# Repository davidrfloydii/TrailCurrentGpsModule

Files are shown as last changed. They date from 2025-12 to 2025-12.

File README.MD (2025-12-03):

# Project Overview
This project is a stand alone GNSS module that utlizes the DFRobot Gravity GNSS receiver. The data that comes in is then formatted and sent over the CAN bus for other modules to use.

Some example use cases are:
-  Digital Clocks
-  Navigation devices
-  Geospatial macros that control devices based on pinned locations

## Enums for GNSS Mode
 -- 1   eGPS              use gps
 -- 2   eBeiDou           use beidou
 -- 3   eGPS_BeiDou       use gps + beidou
 -- 4   eGLONASS          use glonass
 -- 5   eGPS_GLONASS      use gps + glonass
 -- 6   eBeiDou_GLONASS   use beidou +glonass
 -- 7   eGPS_BeiDou_GLONASS use gps + beidou + glonass

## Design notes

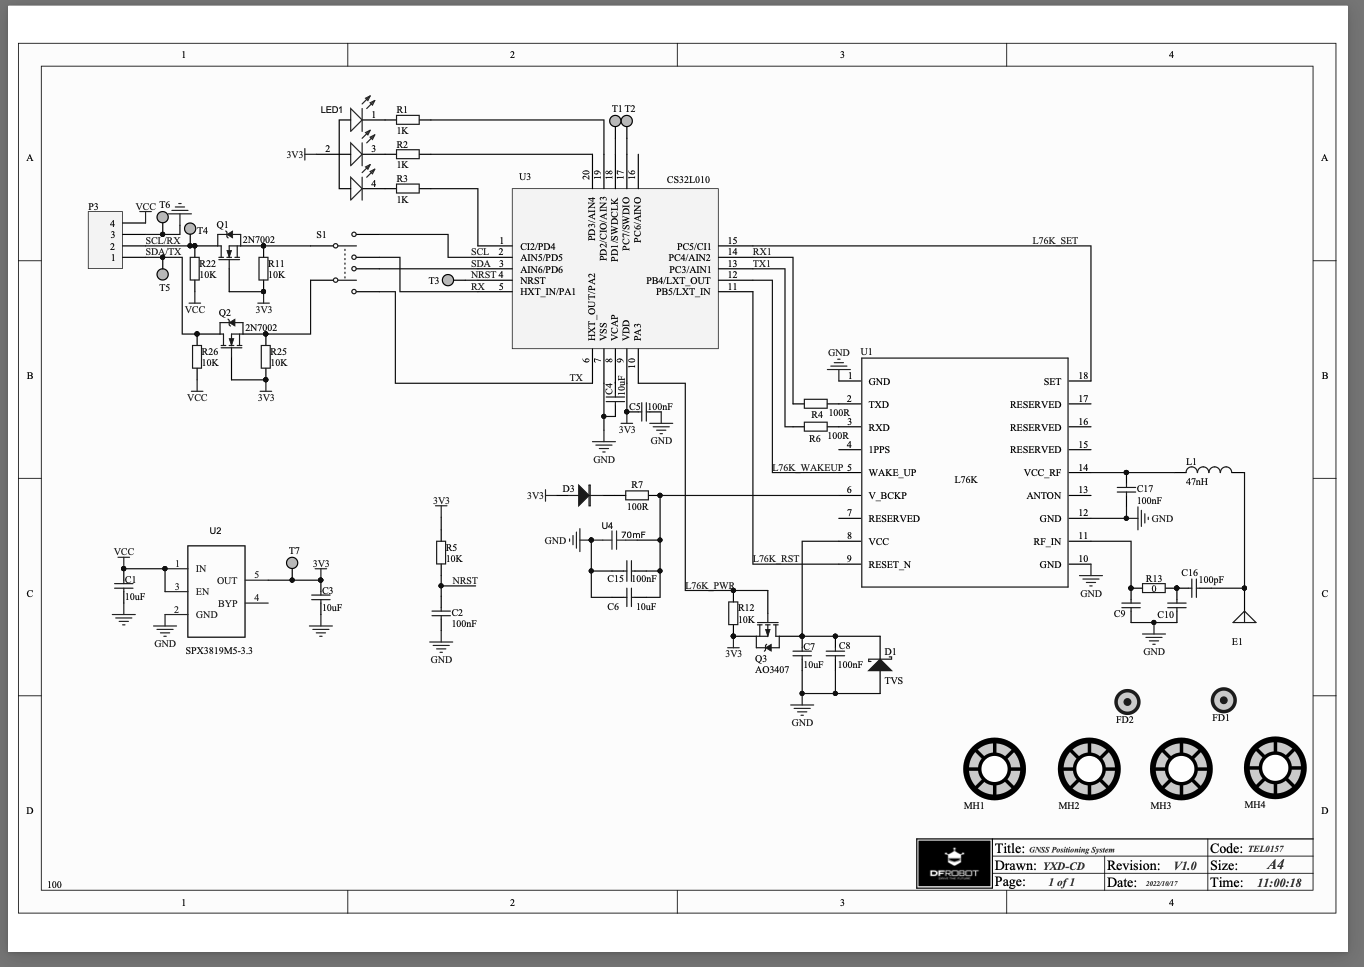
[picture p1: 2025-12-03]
EDA/DFRobot_Gnss_Schematic.png

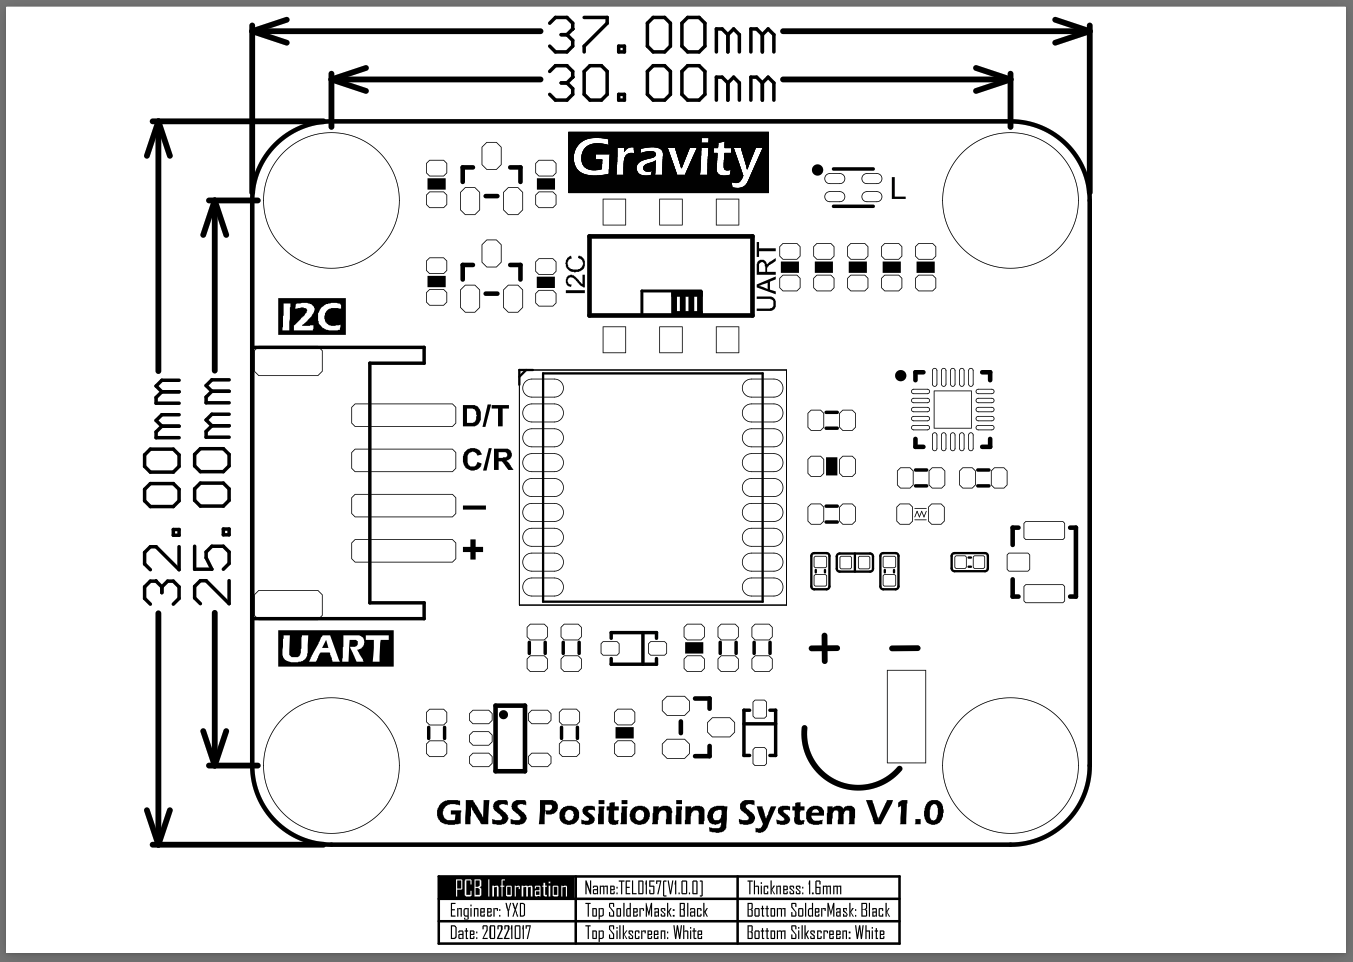
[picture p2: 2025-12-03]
CAD/DFRobotGnss.png

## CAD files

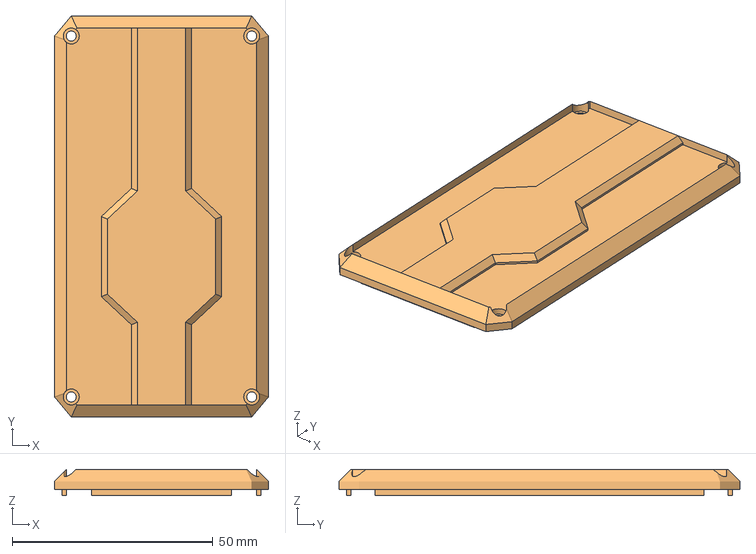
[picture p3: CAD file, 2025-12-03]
CAD/trailcurrent-gps-module-housing.FCStd
53.4 x 100.0 x 6.50 mm
BodyCaseCover
BodyCaseCover (Meshed)

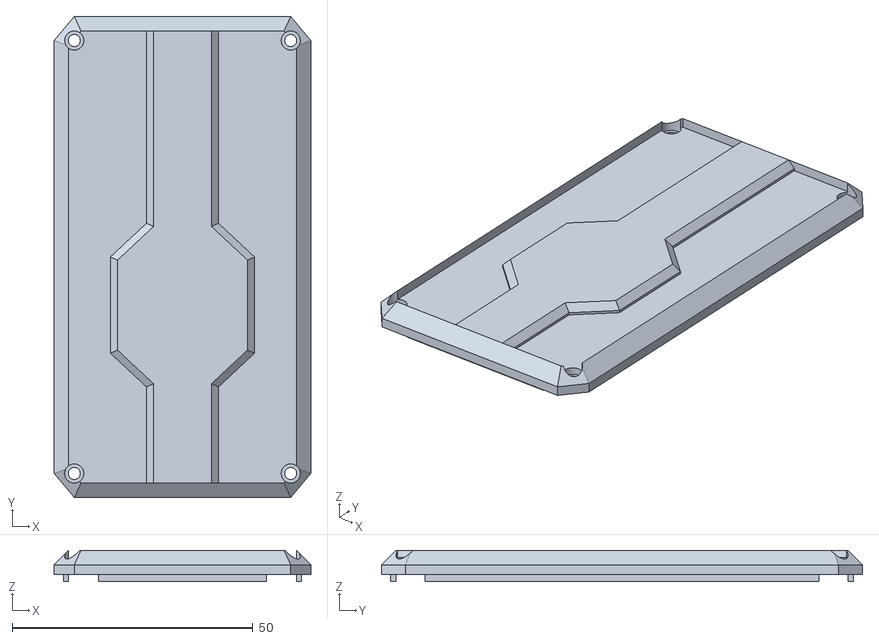
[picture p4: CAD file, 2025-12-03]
CAD/BodyCaseCover.stl
53.4 x 100.0 x 6.50

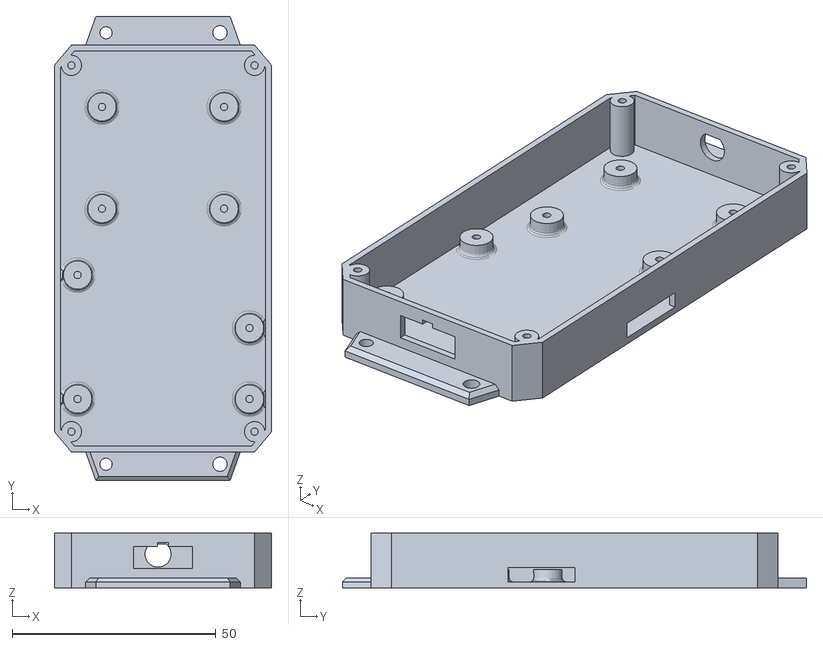
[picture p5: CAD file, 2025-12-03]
CAD/BodyCaseBottom.stl
53.4 x 114.0 x 13.5

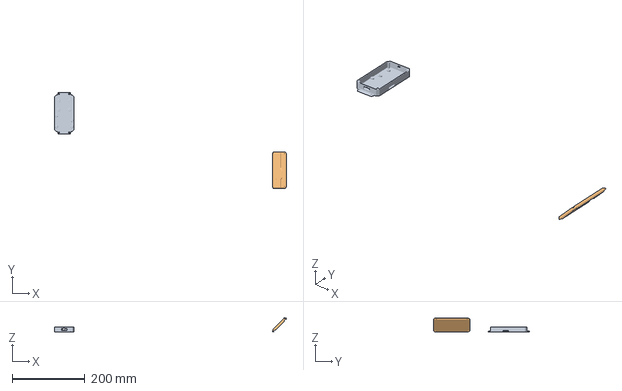
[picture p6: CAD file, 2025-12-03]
CAD/TrailCurrentGpsModuleCaseBottom.3mf
637.7 x 263.6 x 39.2 mm
BodyCaseBottomV4.stl
BodyCaseCover.stl

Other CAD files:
CAD/TrailCurrentGpsModuleCase.3mf

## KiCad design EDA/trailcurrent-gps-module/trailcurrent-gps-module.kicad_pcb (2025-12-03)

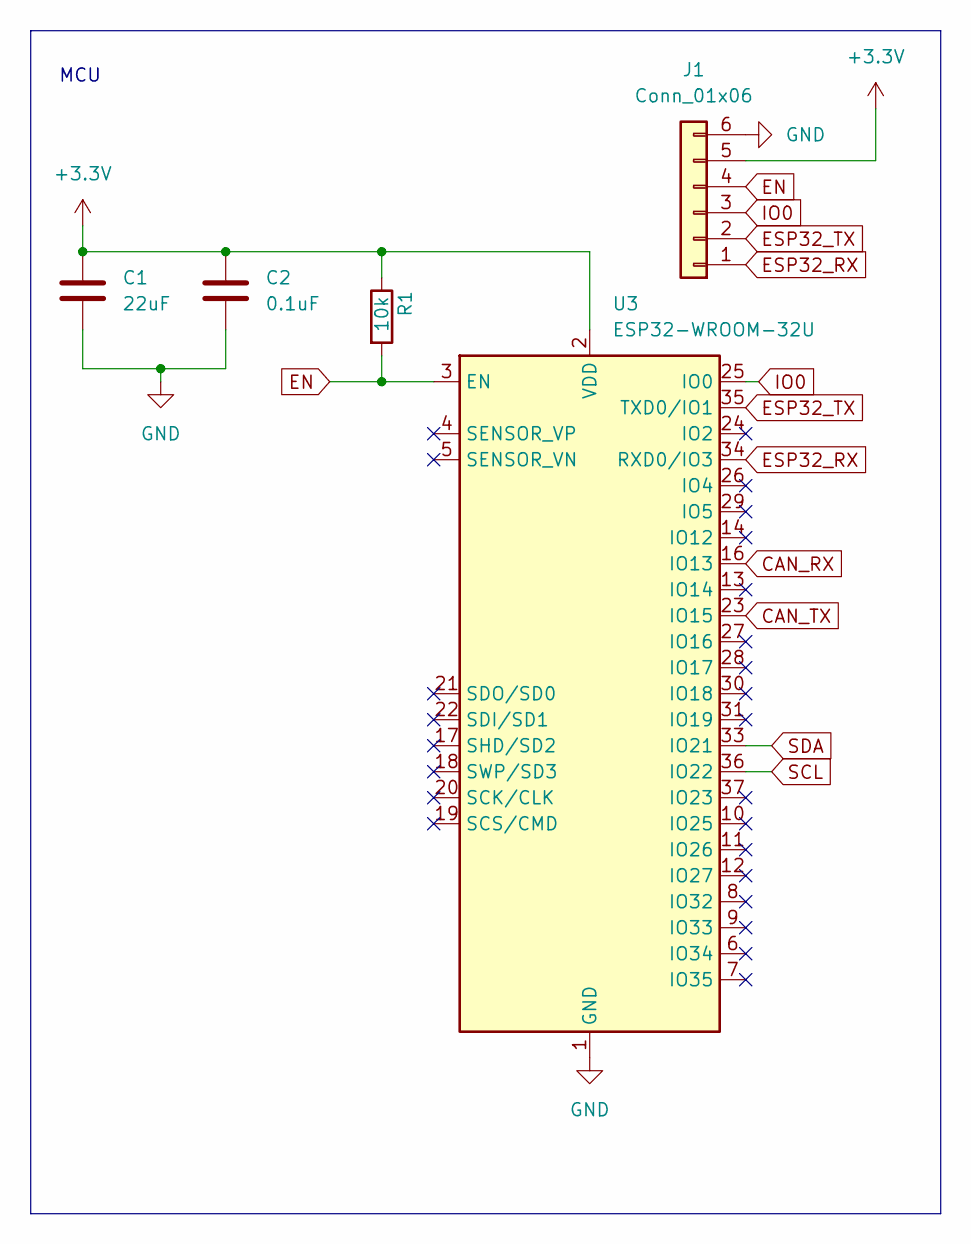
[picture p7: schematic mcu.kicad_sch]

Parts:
C1: 22uF; C_1206_3216Metric_Pad1.33x1.80mm_HandSolder
C2: 0.1uF; C_1206_3216Metric_Pad1.33x1.80mm_HandSolder
J1: Conn_01x06; PinHeader_1x06_P2.54mm_Horizontal
R1: 10k; R_1206_3216Metric_Pad1.30x1.75mm_HandSolder
U3: ESP32-WROOM-32U

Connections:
+3.3V: C1.1, C2.1, J1.5, R1.1, U3.2 (VDD); also elsewhere on the board
CAN_RX: U3.16 (IO13); also elsewhere on the board
CAN_TX: U3.23 (IO15); also elsewhere on the board
EN: J1.4, R1.2, U3.3 (EN)
ESP32_RX: J1.1, U3.34 (RXD0/IO3)
ESP32_TX: J1.2, U3.35 (TXD0/IO1)
GND: C1.2, C2.2, J1.6, U3.1 (GND), U3.15 (GND), U3.38 (GND), U3.39 (GND); also elsewhere on the board
IO0: J1.3, U3.25 (IO0)
SCL: U3.36 (IO22); also elsewhere on the board
SDA: U3.33 (IO21); also elsewhere on the board

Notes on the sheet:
MCU

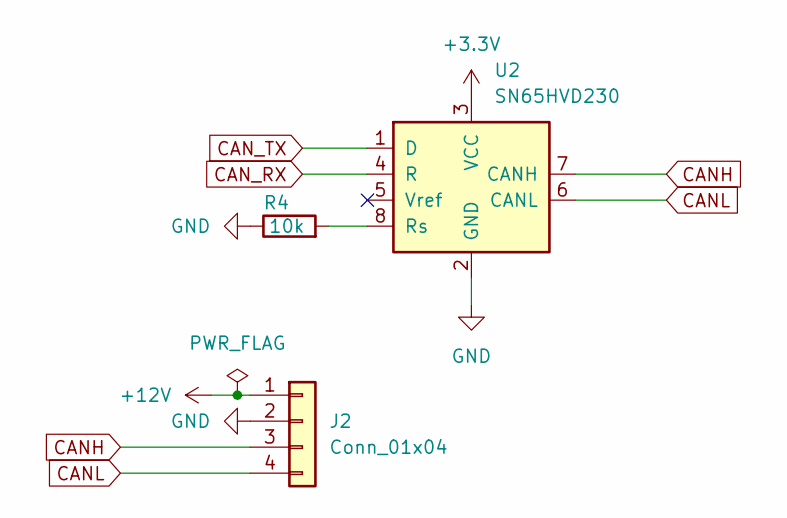
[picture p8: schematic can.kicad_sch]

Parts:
J2: Conn_01x04; CAN_PLUS_POWER
R4: 10k; R_1206_3216Metric_Pad1.30x1.75mm_HandSolder
U2: SN65HVD230; SOIC-8_3.9x4.9mm_P1.27mm

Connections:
+3.3V: U2.3 (VCC); also elsewhere on the board
+12V: J2.1; also elsewhere on the board
CANH: J2.3, U2.7 (CANH)
CANL: J2.4, U2.6 (CANL)
CAN_RX: U2.4 (R); also elsewhere on the board
CAN_TX: U2.1 (D); also elsewhere on the board
GND: J2.2, R4.1, U2.2 (GND); also elsewhere on the board
unnamed: R4.2, U2.8 (Rs)

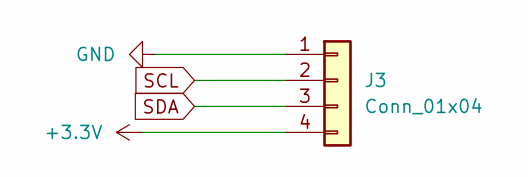
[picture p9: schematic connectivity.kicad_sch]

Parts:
J3: Conn_01x04; GenericPad_01x04

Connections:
+3.3V: J3.4; also elsewhere on the board
GND: J3.1; also elsewhere on the board
SCL: J3.2; also elsewhere on the board
SDA: J3.3; also elsewhere on the board

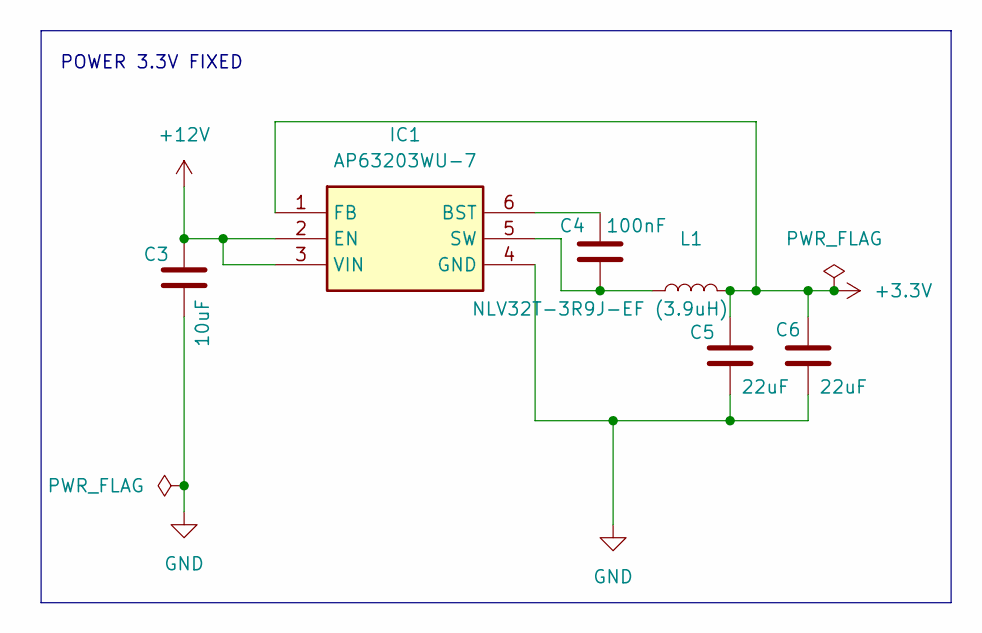
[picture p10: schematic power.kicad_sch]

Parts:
C3: 10uF; C_1206_3216Metric
C4: 100nF; C_1206_3216Metric
C5, C6: 22uF; C_1206_3216Metric_Pad1.33x1.80mm_HandSolder
IC1: AP63203WU-7; AP63203WU7; Mouser Part Number 621-AP63203WU-7
L1: NLV32T-3R9J-EF (3.9uH); NLV32T-3R9J-EF

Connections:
+3.3V: C5.1, C6.1, IC1.1 (FB), L1.2; also elsewhere on the board
+12V: C3.1, IC1.2 (EN), IC1.3 (VIN); also elsewhere on the board
GND: C3.2, C5.2, C6.2, IC1.4 (GND); also elsewhere on the board
unnamed: C4.1, IC1.6 (BST)
unnamed: C4.2, IC1.5 (SW), L1.1

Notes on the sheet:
POWER 3.3V FIXED

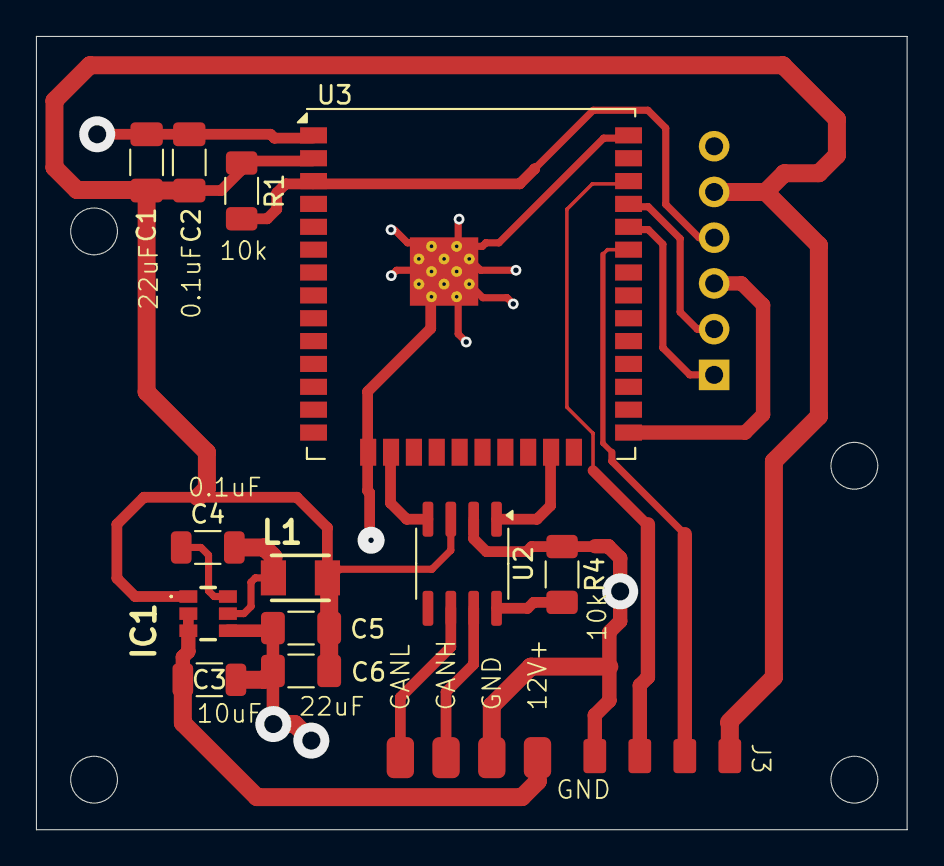
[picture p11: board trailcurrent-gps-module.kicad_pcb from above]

Board: 2 copper layers, 48.4 x 44.1 mm, 15 parts (1 on the bottom side), 16 nets.

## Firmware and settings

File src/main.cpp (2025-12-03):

#include "globals.h"
#include "i2cGps.h"
#include "canHelper.h"

uint16_t currentYear = 0;
uint8_t currentMonth = 0;
uint8_t currentDay = 0;
uint8_t currentHour = 0;
uint8_t currentMinute = 0;
uint8_t currentSecond = 0;
float currentLatitude = 0.0;
float currentLongitude = 0.0;
double currentAltitude = 0.0;
uint8_t currentNumSatUsed = 0;
double currentSpeedOverGround = 0.0;
double currentCourseOverGround = 0.0;
uint8_t currentGnssMode = 0;

unsigned long updateStartMillis;
unsigned long currentUpdateMillis;
const unsigned long updateIntervalMillis = 100;

void setup()
{
  Serial.begin(115200);
  i2cGps::setup();
  canHelper::setup();
}

void loop()
{
  currentUpdateMillis = millis();
  if (currentUpdateMillis - updateStartMillis >= updateIntervalMillis)
  {
    i2cGps::getGnssData(currentYear, currentMonth, currentDay, currentHour, currentMinute, currentSecond, currentLatitude, currentLongitude, currentAltitude, currentNumSatUsed, currentSpeedOverGround, currentCourseOverGround, currentGnssMode);
    canHelper::sendGnssData(currentYear, currentMonth, currentDay, currentHour, currentMinute, currentSecond, currentLatitude, currentLongitude, currentAltitude, currentNumSatUsed, currentSpeedOverGround, currentCourseOverGround, currentGnssMode);
    updateStartMillis = currentUpdateMillis;
  }
}

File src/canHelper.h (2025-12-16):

#pragma once
#include <Arduino.h>
#include "globals.h"
#include "driver/twai.h"

#define CAN_RX 13
#define CAN_TX 15
#define POLLING_RATE_MS 100
static bool driver_installed = false;
#define CAN_SEND_MESSAGE_LATLON_IDENTIFIER 0x009;
#define CAN_SEND_MESSAGE_DATETIME_IDENTIFIER 0x006;
#define CAN_SEND_MESSAGE_SATNUM_SPEED_COURSE_GNSSMODE_IDENTIFIER 0x007;
#define CAN_SEND_MESSAGE_ALTITUDE_IDENTIFIER 0x008;

namespace canHelper
{
    void setup()
    {
        twai_general_config_t g_config = TWAI_GENERAL_CONFIG_DEFAULT((gpio_num_t)CAN_TX, (gpio_num_t)CAN_RX, TWAI_MODE_NO_ACK);
        twai_timing_config_t t_config = TWAI_TIMING_CONFIG_500KBITS(); // Look in the api-reference for other speed sets.
        // THIS IS A FILTER THAT ENSURES TRANSMIT ONLY
        twai_filter_config_t f_config = {
            .acceptance_code = 0xFFFFFFFF, // Base ID = 0
            .acceptance_mask = 0x00000000, // Match exactly against the mask
            .single_filter = true          // Single filter mode
        };
        // twai_filter_config_t f_config = TWAI_FILTER_CONFIG_ACCEPT_ALL();
        //  Install TWAI driver
        if (twai_driver_install(&g_config, &t_config, &f_config) == ESP_OK)
        {
            debugln("Driver installed");
        }
        else
        {
            debugln("Failed to install driver");
            return;
        }

        // Start TWAI driver
        if (twai_start() == ESP_OK)
        {
            debugln("Driver started");
        }
        else
        {
            debugln("Failed to start driver");
            return;
        }

        // Reconfigure alerts to detect frame receive, Bus-Off error and RX queue full states
        uint32_t alerts_to_enable = TWAI_ALERT_RX_DATA | TWAI_ALERT_ERR_PASS | TWAI_ALERT_BUS_ERROR | TWAI_ALERT_RX_QUEUE_FULL;
        if (twai_reconfigure_alerts(alerts_to_enable, NULL) == ESP_OK)
        {
            debugln("CAN Alerts reconfigured");
        }
        else
        {
            debugln("Failed to reconfigure alerts");
            return;
        }

        // TWAI driver is now successfully installed and started
        driver_installed = true;
    }

    byte latBytes[4];
    byte lonBytes[4];
    byte latLonByteAry[8];
    byte dateTimeByteAry[8];
    byte courseOverGroundByteAry[2];
    byte speedOverGroundByteAry[2];
    byte altitudeByteAry[4];
    // Endcode a latitude or longitude float value into a 4-byte array with the first byte as sign
    void encodeLatOrLonValue(float f, byte out[4])
    {
        // Sign byte
        out[0] = (f < 0) ? 1 : 0;
        if (f < 0)
            f = -f;

        // Scale and round
        uint32_t scaled = (uint32_t)(f * 10000.0f + 0.5f);

        // Store 24-bit integer
        out[1] = (scaled >> 16) & 0xFF;
        out[2] = (scaled >> 8) & 0xFF;
        out[3] = scaled & 0xFF;
    }
    // Decode a latitude or longitude float value from a 4-byte array with the first byte as sign
    float decodeLatOrLonValue(const byte in[4])
    {
        uint32_t scaled =
            ((uint32_t)in[1] << 16) |
            ((uint32_t)in[2] << 8) |
            (uint32_t)in[3];

        float f = scaled / 10000.0f;
        if (in[0] == 1)
            f = -f;
        debuglnf(f, 5);
        return f;
    }
    // Method that can be used to decode date and time data from a CAN message
    void decodeDateTimeData(const byte in[8], uint16_t &year, uint8_t &month, uint8_t &day, uint8_t &hour, uint8_t &minute, uint8_t &second)
    {
        year = ((uint16_t)in[0] << 8) | (uint16_t)in[1];
        month = in[2];
        day = in[3];
        hour = in[4];
        minute = in[5];
        second = in[6];
    }
    // Method that can be used to decode altitude data from a CAN message
    void decodeAltitudeData(const byte in[4])
    {
        double altitude = 0.0;
        uint32_t scaled =
            ((uint32_t)in[0] << 24) |
            ((uint32_t)in[1] << 16) |
            ((uint32_t)in[2] << 8) |
            (uint32_t)in[3];
        altitude = scaled / 100.0;
    }

    void formatDateTimeData(uint16_t year, uint8_t month, uint8_t day, uint8_t hour, uint8_t minute, uint8_t second)
    {
        // Implementation for formatting date and time data into CAN message
        dateTimeByteAry[0] = (year >> 8) & 0xFF;
        dateTimeByteAry[1] = year & 0xFF;
        dateTimeByteAry[2] = month;
        dateTimeByteAry[3] = day;
        dateTimeByteAry[4] = hour;
        dateTimeByteAry[5] = minute;
        dateTimeByteAry[6] = second;
        dateTimeByteAry[7] = 0; // Reserved for future use or padding
    }

    void formatLatLongData(float latitude, float longitude)
    {
        encodeLatOrLonValue(latitude, canHelper::latBytes);
        encodeLatOrLonValue(longitude, canHelper::lonBytes);
        latLonByteAry[0] = latBytes[0];
        latLonByteAry[1] = latBytes[1];
        latLonByteAry[2] = latBytes[2];
        latLonByteAry[3] = latBytes[3];
        latLonByteAry[4] = lonBytes[0];
        latLonByteAry[5] = lonBytes[1];
        latLonByteAry[6] = lonBytes[2];
        latLonByteAry[7] = lonBytes[3];
    }

    void formatCourseOverGroundData(double courseOverGround)
    {
        uint16_t scaled = (uint16_t)(courseOverGround * 10.0 + 0.5);
        courseOverGroundByteAry[0] = (scaled >> 8) & 0xFF;
        courseOverGroundByteAry[1] = scaled & 0xFF;
    }

    void formatSpeedOverGroundData(double speedOverGround)
    {
        uint16_t scaled = (uint16_t)(speedOverGround * 100.0);
        speedOverGroundByteAry[0] = (scaled >> 8) & 0xFF;
        speedOverGroundByteAry[1] = scaled & 0xFF;
    }

    void formatAltitudeData(double altitude)
    {
        uint32_t scaled = (uint32_t)(altitude * 100.0);
        altitudeByteAry[0] = (scaled >> 24) & 0xFF;
        altitudeByteAry[1] = (scaled >> 16) & 0xFF;
        altitudeByteAry[2] = (scaled >> 8) & 0xFF;
        altitudeByteAry[3] = scaled & 0xFF;
        decodeAltitudeData(altitudeByteAry);
    }

    void sendDateTimeCanMessage(uint16_t year, uint8_t month, uint8_t day, uint8_t hour, uint8_t minute, uint8_t second)
    {
        if (!driver_installed)
        {
            debugln("TWAI driver not installed, cannot send message");
            return;
        }

        twai_message_t message;
        message.identifier = CAN_SEND_MESSAGE_DATETIME_IDENTIFIER;
        message.data_length_code = 7;
        message.data[0] = (year >> 8) & 0xFF;
        message.data[1] = year & 0xFF;
        message.data[2] = month;
        message.data[3] = day;
        message.data[4] = hour;
        message.data[5] = minute;
        message.data[6] = second;
        message.flags = TWAI_MSG_FLAG_NONE;

        // Transmit message
        if (twai_transmit(&message, pdMS_TO_TICKS(1000)) == ESP_OK)
        {
            debugln("Date/Time CAN message sent");
        }
        else
        {
            debugln("Failed to send Date/Time CAN message");
        }
    }
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

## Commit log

2025-12-03 Starting project, EDA is not complete yet
    [BodyCaseBottom.stl, BodyCaseCover.stl, TrailCurrentGpsModuleCase.3mf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]
2025-12-16 Changed identifier of LatLon to fix bug
    [canHelper.h]
